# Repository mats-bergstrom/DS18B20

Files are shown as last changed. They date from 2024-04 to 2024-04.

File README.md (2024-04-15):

# DS18B20
Use a Raspberry Pi Pico W to read a DS18B20 Temperature sensor and publish data using MQTT.

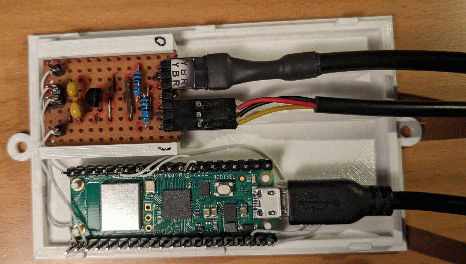
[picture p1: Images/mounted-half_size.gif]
The sensor unit.


The code is written in MicroPython and the basic structure of it is copied from https://github.com/HenrikSolver/picowhanport.

The casing of the unit is modelled in OpenScad and the STL of the bottom and the top cover are in this git.

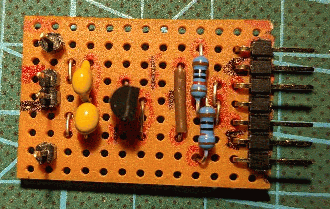
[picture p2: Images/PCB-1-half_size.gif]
The PCB.

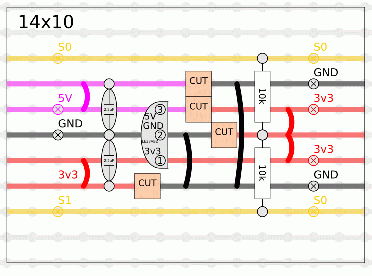
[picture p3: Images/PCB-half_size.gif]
PCB Layout


The PCB takes 5V from the Pico PIN40 VBUS and GND from PIN38 and supplies the 1-Wire sensors with 3v3 using a 100mA regulator.

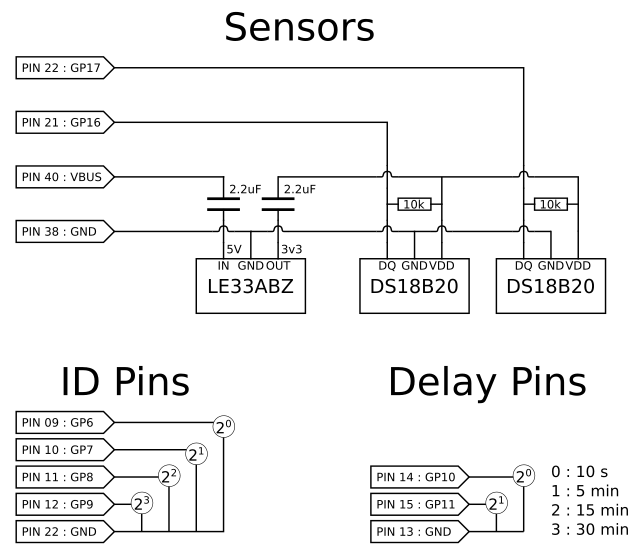
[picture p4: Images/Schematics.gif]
The schematics.


The schematics also show how the strapping of the "ID pins", giving the unit an ID number (0..15) and the "Delay Pins" controlling the measuring interval of the unit.

Files:
| File | Description |
| --- | --- |
| config.py | WLAN and MQTT configuration. |
| boot.py | Just direct execution to main.py. |
| main.py | Main code |
| DS18B20SBS-B.stl | Bottom casing for Pico and PCB |
| DS18B20SBS-top-B.stl | Top casing for Pico and PCB |

## Python Code
You need to edit `config.py` to correcpond to the SSID and PSK of your WLAN.  `MQTTHost` need to be updated to the IP number of your broker to use.

Note that the code (`main.py`) is made to read two independent
one-wire interfaces fed using a 3v3 regulator.  If you only need one,
you need to edit the code.  Depending on your number of sensors, the
Pico's build-in 3v3 might just be able to handle a sensor or two,
depending on the brand of sensor and cable lengths.
Using two different 1-Wire interfaces and the 3v3 regulator greatly
improves the stability of the unit.

The "ID Pins" and the "Delay Pins" are only used at boot time, they are then turned off.

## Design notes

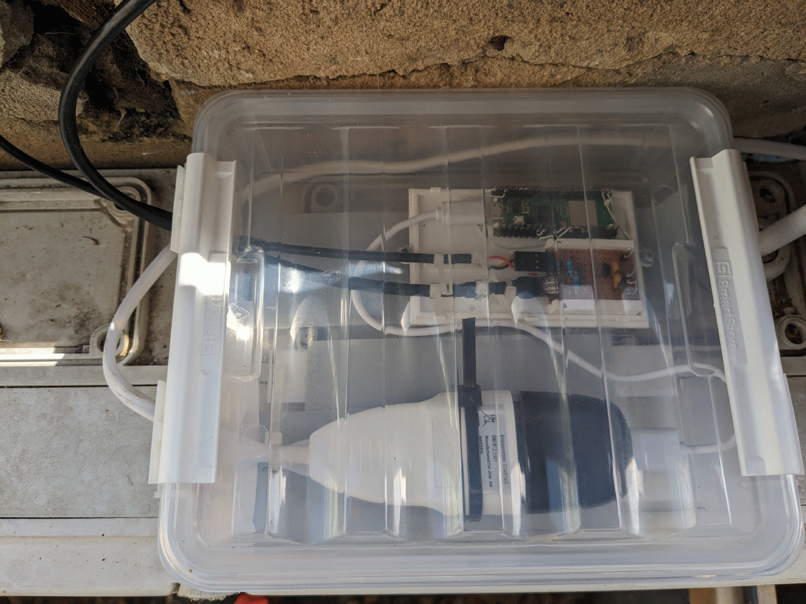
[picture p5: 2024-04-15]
Images/outdoor-box.gif

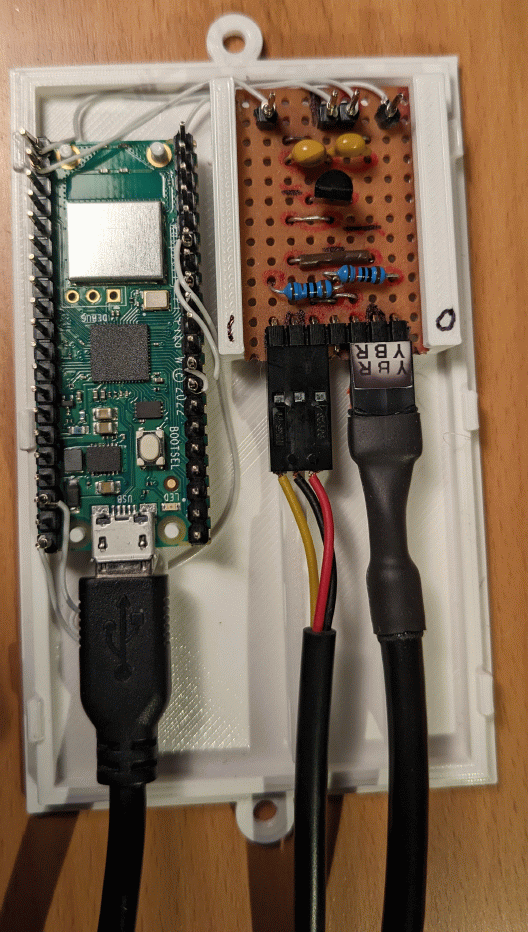
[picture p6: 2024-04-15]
Images/mounted.gif

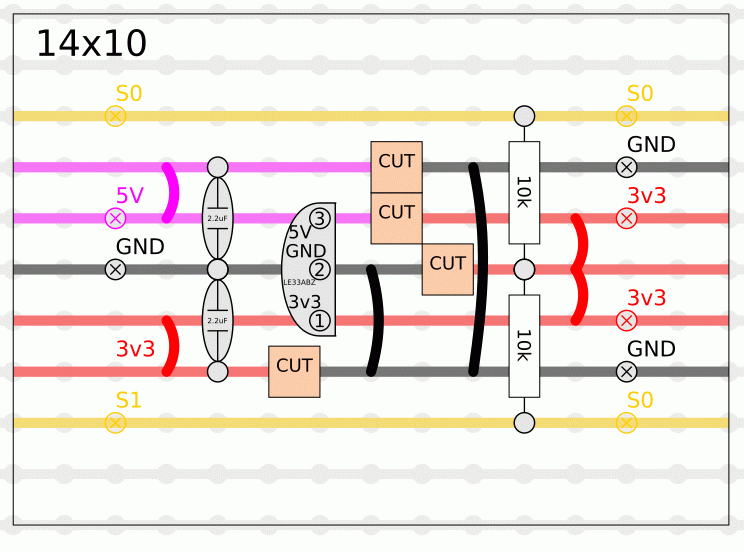
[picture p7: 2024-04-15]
Images/PCB.gif

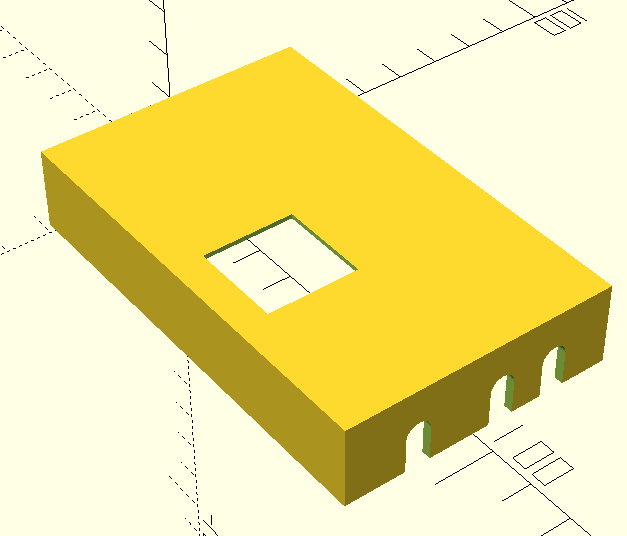
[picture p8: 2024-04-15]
Images/box-top.gif

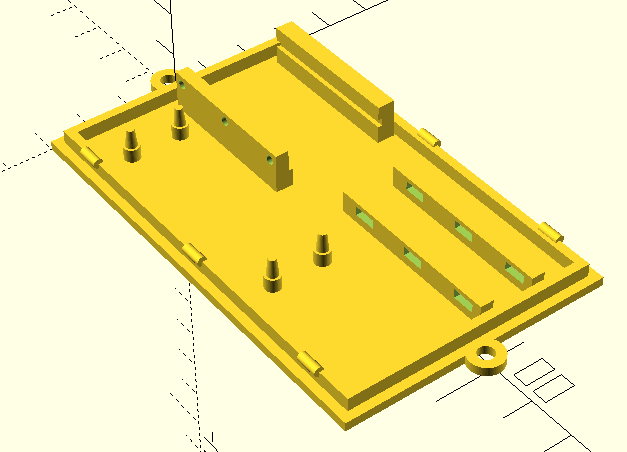
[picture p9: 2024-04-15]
Images/box-bottom.gif

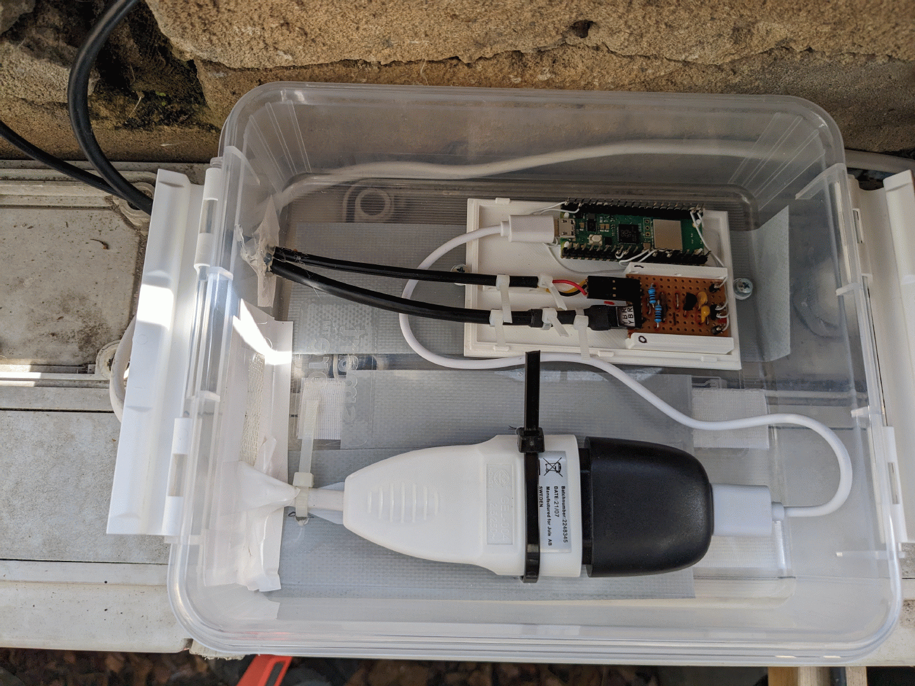
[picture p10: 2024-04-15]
Images/outdoor-box-open.gif

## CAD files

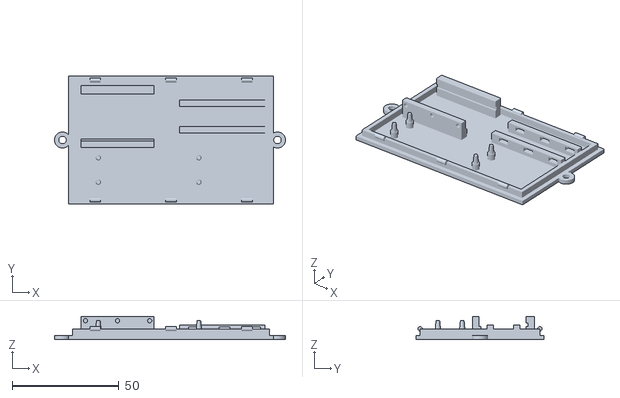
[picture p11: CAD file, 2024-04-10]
DS18B20SBS-B.stl
108.0 x 60.0 x 10.8

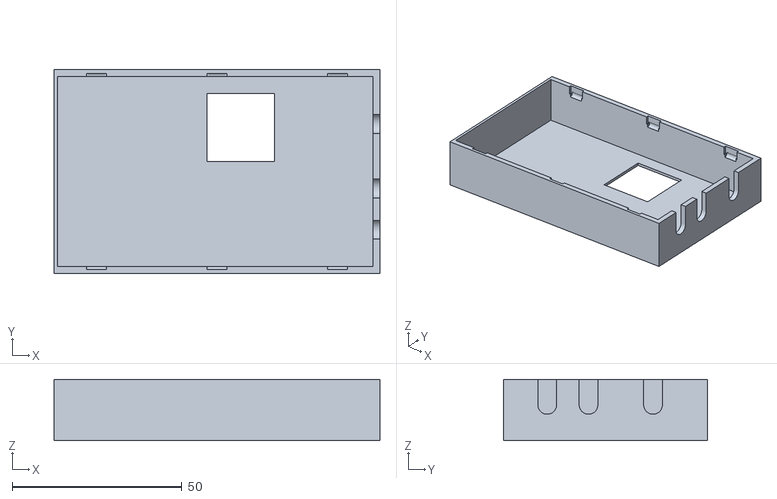
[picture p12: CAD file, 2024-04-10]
DS18B20SBS-top-B.stl
96.0 x 60.0 x 18.0

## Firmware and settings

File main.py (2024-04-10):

# using 2 pins to read the 2 sensors as it is more stable.

import machine, onewire, ds18x20, time, gc
from machine import Pin
from umqtt.simple import MQTTClient
from time import sleep
import network
import config


Pin0 = 16
Pin1 = 17
IDPins = [6,7,8,9]
DelayPins = [10,11]

MQTTTopic0 = 'hus/T%02x/0/T'
MQTTTopic1 = 'hus/T%02x/1/T'



# Get GPIO input from list of pins, note inverted, strapped to GND gives 1
def get_pins( A ):
   rval = 0;
   v = 1;
   for i in A:
      pID = i
      p = Pin( pID, Pin.IN, Pin.PULL_UP )
      pval = p.value()
      p.init( p.IN, p.PULL_DOWN )       # DONE: Pull down to save power!
      if pval == 0:
         rval += v
      v *= 2
   return rval

# Get ID number from pins
def get_ID():
   return get_pins(IDPins)

# Get delay in s from pins
def get_Delay():
   i = get_pins(DelayPins)
   A = [ 
         10,                    # 0: 10s
       5*60,                    # 1:  5min
      15*60,                    # 2: 15min
      30*60                     # 3: 30min
   ]
   if i>3:
      i=3
   return A[i]



# Figure out what ID to use in the topics. pins 6-9 strapped to GND
id = get_ID()
print("ID = %d" % id)

topicT0 = MQTTTopic0 % id
topicT1 = MQTTTopic1 % id
print("topics = " + topicT0 + "," + topicT1)


# Set the hostname
hname = "rPIp_DF12B20_%02x" % id
print("hname = " + hname)

# Set the mqtt client name
cname = hname
print("cname = " + cname)


# Get the delay to use. pins 10-11 strapped to gnd
wait_delay = get_Delay()
print("delay = %d" % wait_delay)


# define the led to blink when we measure.
led = machine.Pin("LED", machine.Pin.OUT)
led.on()

ds_pin0 = machine.Pin(Pin0,machine.Pin.IN)
ds_sensor0 = ds18x20.DS18X20(onewire.OneWire(ds_pin0))

ds_pin1 = machine.Pin(Pin1,machine.Pin.IN)
ds_sensor1 = ds18x20.DS18X20(onewire.OneWire(ds_pin1))


try:
    roms0 = ds_sensor0.scan()
    roms1 = ds_sensor1.scan()
except:
    led.off();
    machine.soft_reset()

led.off();

network.hostname(hname)
wlan = network.WLAN(network.STA_IF)
wlan.active(True)
wlan.connect(config.SSID, config.PSK)


# Connect to the wlan
waitcount = 0
while wlan.status() != 3:
   waitcount+=1
   time.sleep(0.5)
   led.toggle()
   if waitcount > 120:
      led.off()
      machine.reset()

print("WIFI CONNECTED")

#led on when connected to wlan
led.on()
mqc = MQTTClient(cname, config.MQTTHost, 1883)

try:
    mqc.connect()
except:
    led.off();
    machine.soft_reset()

print("MQTT CONNECTED")
led.off();


led.off()
while True:
  led.toggle()
  ds_sensor0.convert_temp()
  led.toggle()
  ds_sensor1.convert_temp()
  led.toggle()
 
  time.sleep_ms(1000)
  led.toggle()

  for rom in roms0:
    T0 = ds_sensor0.read_temp(rom)
    led.toggle()

  for rom in roms1:
    T1 = ds_sensor1.read_temp(rom)
    led.toggle()

  S0 = "{:.1f}".format(T0);
  S1 = "{:.1f}".format(T1);

  print(S0)
  print(S1)

  try:
      mqc.publish(topicT0,S0,True)
      mqc.publish(topicT1,S1,True)
  except:
      led.off();
      machine.soft_reset()

  gc.collect()
  led.off()
  time.sleep(wait_delay)
